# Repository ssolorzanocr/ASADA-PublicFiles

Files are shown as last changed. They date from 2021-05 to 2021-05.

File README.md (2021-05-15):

LoRa based control and log system for ASADA-Samara
============

### Most recent version of this repository can be found in: ###

* [ASADA-PublicFiles](https://github.com/ssolorzanocr/ASADA-PublicFiles)

### What is this repository for? ###

* This repository was created to develop LoRa based embedded control solution for the pumps of ASADA-Samara. 

### HELTEC LoRa 32 board information

* [Documentation page](https://heltec.org/project/wifi-lora-32/)
* [Pinout diagram](https://resource.heltec.cn/download/WiFi_LoRa_32/WIFI_LoRa_32_V2.pdf)
* [Schematic](https://resource.heltec.cn/download/WiFi_LoRa_32/V2/WIFI_LoRa_32_V2(868-915).PDF)
* [ESP32 datasheet](https://www.espressif.com/sites/default/files/documentation/esp32_datasheet_en.pdf) 

### Enclousure

* [Page](https://www.se.com/es/es/product/NSYCRN33200P/spacial-crn-plain-door-with-mount.plate.-h300xw300xd200-ip66-ik10-ral7035../) 

### How do I get set up? ###

* Install Git
* Install Arduino IDE
* Install Heltec ESP32 Library in the Arduino Library Manager
Open Arduino IDE, then Select `Sketch`->`Include Library`->`Manage Libraries...`
Search `Heltec ESP32` and install it.
* Install Adafruit MQTT Library in the Arduino Library Manager
Open Arduino IDE, then Select `Sketch`->`Include Library`->`Manage Libraries...`
Search `Adafruit MQTT` and install it.

### Library source code and examples
* [Adafruit_MQTT_Library](https://github.com/adafruit/Adafruit_MQTT_Library)

### Contribution guidelines ###

* If you want to propose a review or need to modify the code for any reason first clone this [repository](https://github.com/ssolorzanocr/ASADA-PublicFiles) in your PC and create a new branch for your changes. Once your changes are complete and fully tested ask the administrator permission to push this new branch into the source.
* If you just want to do local changes instead you can download a zip version of the repository and do all changes locally in your PC. 

### Who do I talk to? ###

* [Juan J. Rojas](mailto:juan.rojas@itcr.ac.cr)
* [Sergio Solorzano](mailto:solorzanos117@gmail.com)

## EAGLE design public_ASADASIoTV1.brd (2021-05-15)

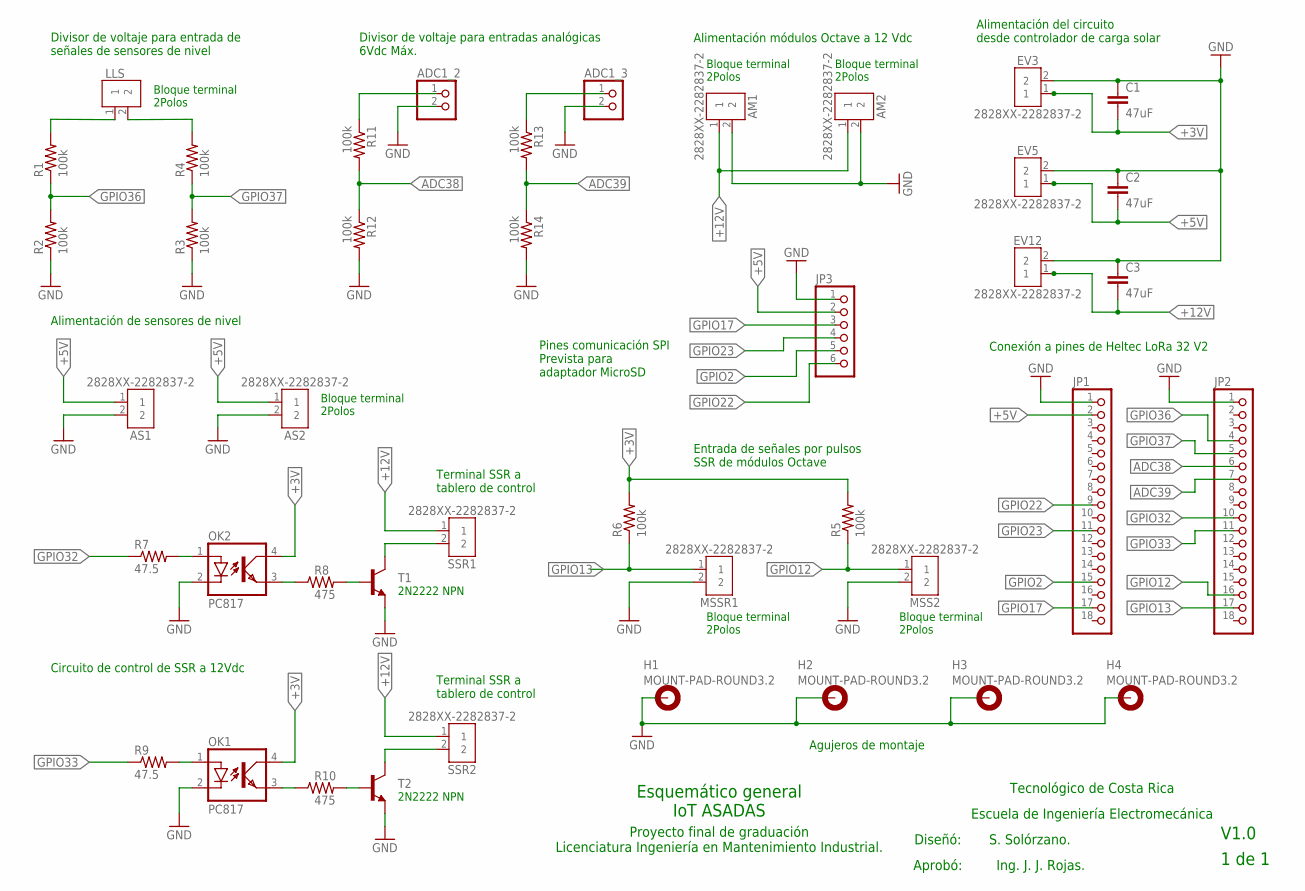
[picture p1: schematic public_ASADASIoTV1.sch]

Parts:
ADC1_2, ADC1_3: PINHD-1X2; 1X02
AM1, AM2: 2828XX-2282837-2; TERMBLK_508-2N
AS1, AS2: 2828XX-2282837-2; TERMBLK_508-2N
C1, C2, C3: 47uF; C2.5-5
EV3, EV5, EV12: 2828XX-2282837-2; TERMBLK_508-2N
H1, H2, H3, H4: MOUNT-PAD-ROUND3.2; 3,2-PAD
JP1, JP2: PINHD-1X18; 1X18
JP3: PINHD-1X6; 1X06
LLS: 2828XX-2282837-2; TERMBLK_508-2N
MSS2: 2828XX-2282837-2; TERMBLK_508-2N
MSSR1: 2828XX-2282837-2; TERMBLK_508-2N
OK1, OK2: PC817; DIL04
R1, R2, R3, R4, R5, R6, R11, R12, R13, R14: 100k; R0805
R7, R9: 47.5; R0805
R8, R10: 475; R0805
SSR1, SSR2: 2828XX-2282837-2; TERMBLK_508-2N
T1, T2: 2N3904; TO92

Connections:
+3V: C1.2, EV3.1, OK1.4 (COL), OK2.4 (COL), R5.2, R6.2
+5V: AS1.1, AS2.1, C2.2, EV5.1, JP1.2, JP3.2
+12V: AM1.1, AM2.1, C3.2, EV12.1, SSR1.1, SSR2.1
ADC38: JP2.6, R11.2, R12.1
ADC39: JP2.7, R13.2, R14.1
GND: ADC1_2.2, ADC1_3.2, AM1.2, AM2.2, AS1.2, AS2.2, C1.1, C2.1, C3.1, EV3.2, EV5.2, EV12.2, H1.B3,2, H2.B3,2, H3.B3,2, H4.B3,2, JP1.1, JP2.1, JP3.1, MSS2.2, MSSR1.2, OK1.2 (C), OK2.2 (C), R2.1, R3.1, R12.2, R14.2, T1.3 (E), T2.3 (E)
GPIO2: JP1.15, JP3.5
GPIO12: JP2.16, MSS2.1, R5.1
GPIO13: JP2.17, MSSR1.1, R6.1
GPIO17: JP1.17, JP3.3
GPIO22: JP1.9, JP3.6
GPIO23: JP1.11, JP3.4
GPIO32: JP2.10, R7.1
GPIO33: JP2.11, R9.1
GPIO36: JP2.4, R1.1, R2.2
GPIO37: JP2.5, R3.2, R4.1
HLS: LLS.2, R4.2
LLS: LLS.1, R1.2
unnamed: OK2.1 (A), R7.2
unnamed: SSR1.2, T1.1 (C)
unnamed: R8.2, T1.2 (B)
unnamed: OK2.3 (EMIT), R8.1
unnamed: ADC1_3.1, R13.1
unnamed: ADC1_2.1, R11.1
unnamed: OK1.1 (A), R9.2
unnamed: R10.2, T2.2 (B)
unnamed: OK1.3 (EMIT), R10.1
unnamed: SSR2.2, T2.1 (C)

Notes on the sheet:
Terminal SSR a tablero de control
Entrada de señales por pulsos SSR de módulos Octave
Alimentación de sensores de nivel
Divisor de voltaje para entrada de señales de sensores de nivel
Alimentación módulos Octave a 12 Vdc
Divisor de voltaje para entradas analógicas 6Vdc Máx.
Alimentación del circuito desde controlador de carga solar
Pines comunicación SPI Prevista para adaptador MicroSD
Agujeros de montaje
Conexión a pines de Heltec LoRa 32 V2
Circuito de control de SSR a 12Vdc
V1.0
1 de 1
Proyecto final de graduación Licenciatura Ingeniería en Mantenimiento Industrial.
Diseñó:
S. Solórzano.
Aprobó:
Ing. J. J. Rojas.
Escuela de Ingeniería Electromecánica
Tecnológico de Costa Rica
Esquemático general IoT ASADAS
2N2222 NPN
Bloque terminal 2Polos

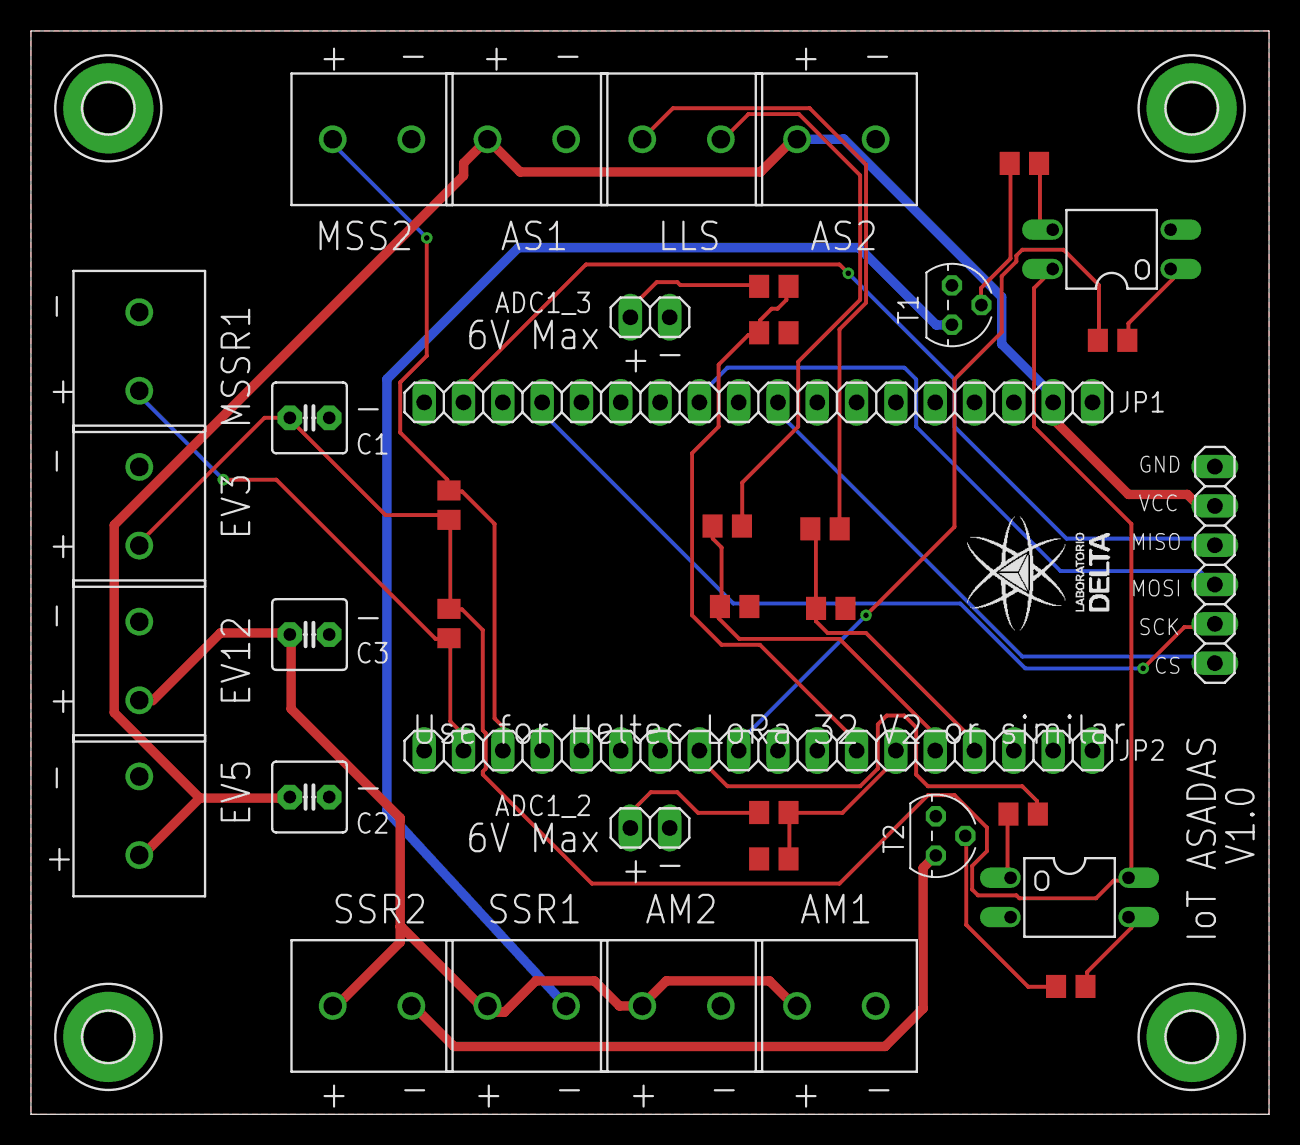
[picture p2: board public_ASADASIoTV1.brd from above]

Board: 2 copper layers, 80.0 x 70.0 mm, 42 parts (0 on the bottom side), 28 nets.

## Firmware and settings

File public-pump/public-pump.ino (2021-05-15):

/**
 * @file pump.ino
 * @author Sergio Solórzano Alfaro
 * @author Juan J. Rojas 
 * @date 15 May 2021
 * @brief Main loop for pump controller and 2 water meter data extraction
 * @par Institution:
 * DeltaLab. Instituto Tecnológico de Costa Rica.
 * @par mail:
 * solorzanos117@gmail.com
 * juan.rojas@tec.ac.cr
 * @par Git repository:
 * https://github.com/ssolorzanocr/ASADA-PublicFiles
 */

/*SS: IMPORTANT: When using GPIO pins to receive PWM signals and sending by LoRa, I recommend using pins 12 and 13. 
*Any other may have internal hardware interference*/

#include "heltec.h"
#include "soc/rtc.h"
#include "FS.h"
#include "SD.h"
#include <SPI.h>
#include <time.h>

#define BAND    915E6   //you can set band here directly,e.g. 868E6 (Europe),915E6 (North America),433E6 (Asia)

//Micro TF card pins to ESP32 GPIOs via this connecthin:
#define SD_CS   22        //  SD_CS   -- GPIO22
#define SD_SCK  2         //  SD_SCK  -- GPIO2
#define SD_MOSI 23        //  SD_MOSI -- GPIO23
#define SD_MISO 17        //  SD_MISO -- GPIO17

#define DIGITAL_PULSE_1 13  //for hidric measures  
#define DIGITAL_PULSE_2 12  //for hidric measures
#define ADC_BATTERY     38  //battery voltage input
#define ADC_INPUT       39  //foreseen input

#define DIGITAL_INPUT_1 36  //for 15hp pump contactor relay state
#define DIGITAL_INPUT_2 37  //for 10hp pump contactor relay state 

#define DIGITAL_SSROUT_1 32  //to activate 15hp pump contactor relay 
#define DIGITAL_SSROUT_2 33  //to activate 10hp pump contactor relay 

#define RP1     0.01          //IMPORTANT: Rp stands for "Pulse Resolution". Depends on flow meter parameters. 1 pulse = Rp cubic meters of water that have passed.
#define RP2     0.01
#define UNITS   1000000000.0  //calculate flow: (1000000000*Rp/(sum_interval/pulses))[m3/s]; (3600000000*Rp/(sum_interval/pulses))[m3/h]; (1000000000*Rp/(sum_interval/pulses))[L/s]

// The sd card can also use a virtual SPI bus
SPIClass sd_spi(HSPI);
long timezone = 1;
byte daysavetime = 1;

char t_stamp[20]; char buff[70] = {'\0'}; char value[20]; char semicolon[] = ";"; char newline[] = "\n"; char tank_rssi[10] = {'\0'};


TaskHandle_t measureTask;
TaskHandle_t loopTask;

/*----Local variables----*/    
byte localAddress;    // address of this device
byte destination;     // destination to send to (Gateway)
String incoming;

char *strtok(char *str1, const char *str2); char *part; char charpacket [80]; char delimiter [2] = "e";
String packSize = "--"; String sdelimiter="e";
char *s; int8_t packflag; 
char mpack[] = {'\0'};
char ppack[8] = {'\0'};

String pump15hp_status, pump1 = "OFF";
String pump10hp_status, pump2 = "OFF";
double battery_voltage, battery_life;
double pump15hp_flow, pump15hp_vol, pump15hp_vol_sent, pump10hp_flow, pump10hp_vol, pump10hp_vol_sent, av15hp_flow, av10hp_flow;

uint32_t t1_interval, t2_interval, sum1_interval, init_1stamp, sum2_interval, init_2stamp, last1interval, last2interval, lastorder;
bool first_1flag = 0; bool first_2flag = 0; bool firstflow1_flag, firstflow2_flag;
bool meter_1flag, meter_2flag;
/* create a hardware timer */
hw_timer_t * timer = NULL;
bool timer_flag, sd_flag; bool message_flag = 0;


int8_t txPower = 20;       /*txPower -- 0 ~ 20 dBm*/
/** LoRa.setTxPower(txPower,RFOUT_pin);
  * txPower -- 0 ~ 20
  * RFOUT_pin could be RF_PACONFIG_PASELECT_PABOOST or RF_PACONFIG_PASELECT_RFO
  *   - RF_PACONFIG_PASELECT_PABOOST -- LoRa single output via PABOOST, maximum output 20dBm
  *   - RF_PACONFIG_PASELECT_RFO     -- LoRa single output via RFO_HF / RFO_LF, maximum output 14dBm
  */ 

void IRAM_ATTR pulsecountA(){ 
  meter_1flag = 1;
}
void IRAM_ATTR pulsecountB(){ 
  meter_2flag = 1;
}

void IRAM_ATTR timer_isr(){
  timer_flag = 1;
}

void setup() {
  Serial.begin(115200);
  delay(10);
  noInterrupts();     //Disable interrupts while initiating 
  pinMode(DIGITAL_PULSE_1, INPUT_PULLUP); pinMode(DIGITAL_PULSE_2, INPUT_PULLUP); 
  pinMode(DIGITAL_SSROUT_1,OUTPUT); pinMode(DIGITAL_SSROUT_2,OUTPUT);
  pinMode(DIGITAL_INPUT_1,INPUT); pinMode(DIGITAL_INPUT_2,INPUT);
  attachInterrupt(DIGITAL_PULSE_1,&pulsecountA,RISING);      //(Interrupción (GPIO13),función,Flanco de subida)
  attachInterrupt(DIGITAL_PULSE_2,&pulsecountB,RISING);
  
  /* 1 tick take 1/(80MHZ/80) = 1us so we set divider 80 and count up */
  timer = timerBegin(0, 80, true);
  /* Attach timer_isr function to our timer */
  timerAttachInterrupt(timer, &timer_isr, true);
  /* Set alarm to call onTimer function every second 1 tick is 1us
  => 1 second is 1000000us */
  /* Repeat the alarm (third parameter) */
  timerAlarmWrite(timer, 5000000, true);
  /* Start an alarm */
  timerAlarmEnable(timer);

  Heltec.begin(true /*DisplayEnable Enable*/, true /*Heltec.Heltec.Heltec.LoRa Disable*/, true /*Serial Enable*/, true /*PABOOST Enable*/, BAND /*long BAND*/);
  Heltec.display->init();
  Heltec.display->setTextAlignment(TEXT_ALIGN_LEFT);
  Heltec.display->setFont(ArialMT_Plain_10); Heltec.display->flipScreenVertically();  
  Heltec.display->clear();
  Heltec.display->drawString(0, 0, "Heltec.LoRa Initial success!");
  Heltec.display->drawString(0, 20, "Beginning PUMP program!");
  Heltec.display->display();
  Serial.print("setup running on core "); Serial.println(xPortGetCoreID());
  
  //create a task that will be executed in the measureTaskcode() function, with priority 1 and executed on core 1
  xTaskCreatePinnedToCore(
                    measureTaskcode,  /* Task function. */
                    "measure",        /* name of task. */
                    10000,            /* Stack size of task */
                    NULL,             /* parameter of the task */
                    1,                /* priority of the task */
                    &measureTask,     /* Task handle to keep track of created task */
                    1);               /* pin task to core */                  
  delay(200);

  //create a task that will be executed in the loopTaskcode() function, with priority 1 and executed on core 0
  xTaskCreatePinnedToCore(
                    loopTaskcode,   /* Task function. */
                    "loop",         /* name of task. */
                    10000,          /* Stack size of task */
                    NULL,           /* parameter of the task */
                    1,              /* priority of the task */
                    &loopTask,      /* Task handle to keep track of created task */
                    0);             /* pin task to core */                  
  delay(200);

  // SD Card productionData.csv file initiation
  sd_spi.begin(SD_SCK, SD_MISO, SD_MOSI, SD_CS);

  if (!SD.begin(SD_CS, sd_spi)){
      Serial.println("SD Card: mounting failed.");
  } else {
      Serial.println("SD Card: mounted.");
  }
  uint8_t cardType = SD.cardType();

  if(cardType == CARD_NONE){
      Serial.println("No SD card attached");
      sd_flag=0;
      return;   //exit setup
  }else{
    sd_flag=1;
  }

  Serial.print("SD Card Type: ");
  if(cardType == CARD_MMC){
      Serial.println("MMC");
  } else if(cardType == CARD_SD){
      Serial.println("SDSC");
  } else if(cardType == CARD_SDHC){
      Serial.println("SDHC");
  } else {
      Serial.println("UNKNOWN");
  }
  uint64_t cardSize = SD.cardSize() / (1024 * 1024);
  Serial.printf("SD Card Size: %lluMB\n", cardSize);

  //For new SD Cart use only
  //deleteFile(SD, "/productionData.csv");
  //writeFile(SD, "/productionData.csv", "time;Flw1;Vol1;Flw2;Vol2;VBat\n");
  
  readFile(SD, "/productionData.csv");
  delay(500);
}


void measureTaskcode( void * pvParameters ){
  delay(6000);        //waits for everything else to start
  Serial.print("measureTask() running on core "); Serial.println(xPortGetCoreID());
  interrupts();       //Enable interrupts
  
  for(;;){            //measure loop for 2 simultaneous Octave water meters
    //After 71.6 minutes (2^32 micro seconds), the value you get from micros() will overflow (reset to zero).
    //Acording to Octave –After 1 minute of no flow, the meter will flash a series of letters and numbers in place of the rate of flow to show the checksum of the software version. 
    
    if(first_1flag){                         //Check only when measuring
      if ((micros()-init_1stamp)>120000000){  //Stop and reset measure process after 2 minutes of no PULSES. **Min flow posibly measured = RP*1000/120 [L/s]
        first_1flag=0; 
        pump15hp_flow = 0;
        sum1_interval+=(micros()-init_1stamp);    //Add last large time interval for average calc 
        if (firstflow1_flag){
          av15hp_flow = UNITS*(pump15hp_vol-RP1)/(double)sum1_interval; //minus Rp cause first pulse measure does not count for first flow calc
        }else{
          av15hp_flow = UNITS*(pump15hp_vol)/(double)sum1_interval;
        }
        Serial.println("Stop 15hp");              //Measuring process stops in order to save memory

        //printing >>>
        //time,interval between pulses (us),vol(m3),flow(L/s),promflow(L/s),interval between pulses (us),vol(m3),flow(L/s),promflow(L/s),battery voltage
        Serial.print(",");Serial.print(last1interval);Serial.print(","); Serial.print (pump15hp_vol,3); Serial.print(","); 
        Serial.print (pump15hp_flow,4); Serial.print(","); Serial.print(av15hp_flow,4); Serial.print(", , , , ,"); 
        Serial.println(battery_voltage,4);
        Serial.println(sum1_interval);
      }
    }
    if(first_2flag){                         //Check only when measuring
      if ((micros()-init_2stamp)>120000000){  //Stop and reset measure process after 2 minutes of no PULSES. **Min flow posibly measured = RP*1000/120 [L/s]
        first_2flag=0; 
        pump10hp_flow = 0;
        sum2_interval+=(micros()-init_2stamp);    //Add last large time interval for average calc 
        if (firstflow2_flag){
          av10hp_flow = UNITS*(pump10hp_vol-RP2)/(double)sum2_interval; //minus Rp cause first pulse measure does not count for first flow calc
        }else{
          av10hp_flow = UNITS*(pump10hp_vol)/(double)sum2_interval;
        }
        Serial.println("Stop 10hp");              //Measuring process stops in order to save memory

        //printing >>>
        //time,interval between pulses (us),vol(m3),flow(L/s),promflow(L/s),interval between pulses (us),vol(m3),flow(L/s),promflow(L/s),battery voltage
        Serial.print(", , , , ,"); 
        Serial.print(last2interval);Serial.print(","); Serial.print (pump10hp_vol,3); Serial.print(","); 
        Serial.print (pump10hp_flow,4); Serial.print(","); Serial.print(av10hp_flow,4); Serial.print(",");
        Serial.println(battery_voltage,4);
        Serial.println(sum2_interval);
      }
    }
    
    //Start measures
    if(meter_1flag && !first_1flag){  //Start 15hp measure process 
      first_1flag=1; meter_1flag=0; firstflow1_flag=1; Serial.println("Start 15hp");
      init_1stamp=micros();          //First time stamp
      pump15hp_vol+= RP1;                     //First volume measure
    }
    if(meter_2flag && !first_2flag){  //Start 10hp measure process 
      first_2flag=1; meter_2flag=0; firstflow2_flag=1; Serial.println("Start 10hp");
      init_2stamp=micros();          //First time stamp
      pump10hp_vol+= RP2;                     //First volume measure
    }
    
    //Measuring volume and flow process for 15hp pump
    if(meter_1flag && first_1flag ){
      t1_interval=abs(micros()-init_1stamp);  //Time interval between pulses
      if (t1_interval<110000){       //IGNORE SMALL INTERFERENCES, THAT CAUSES HUGE FLOW MEASURES < 0.3 sec 
        //IMPORTANT: THIS PARAMETER MUST BE A LITTLE BIT LARGER THAN PULSE WIDTH ---> SMALL PULSE WIDTHS HELPS AT MEASURING
        //pulse width measured for 4in Octave is 450ms and for 2in Octave is 300ms
        //pulse width programed for 4in Octave is 90ms and for 2in Octave is 280ms
        meter_1flag=0;
      }else{
        init_1stamp=micros();        //Time stamp for next measure
        sum1_interval+=t1_interval;   //For average flow calc
        
        pump15hp_flow = (UNITS*RP1)/((double)t1_interval); 
        
        pump15hp_vol+= RP1;                                 //plus Rp cubic meters per interruption

        if (firstflow1_flag){
          av15hp_flow = UNITS*(pump15hp_vol-RP1)/(double)sum1_interval; //minus Rp cause first pulse measure does not count for first flow calc
        }else{
          av15hp_flow = UNITS*(pump15hp_vol)/(double)sum1_interval;
        }
        meter_1flag=0; last1interval= t1_interval;
        
        //printing >>>
        //time,interval between pulses (us),vol(m3),flow(L/s),promflow(L/s),interval between pulses (us),vol(m3),flow(L/s),promflow(L/s),battery voltage
        Serial.print(",");Serial.print(last1interval);Serial.print(","); Serial.print (pump15hp_vol,3); Serial.print(","); 
        Serial.print (pump15hp_flow,4); Serial.print(","); Serial.print(av15hp_flow,4); Serial.print(", , , , ,"); 
        Serial.println(battery_voltage,4);
        Serial.println(sum1_interval);
      } 
    }
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
void loop () {
  delay(1000);
}
/*--------------------------------------------------------------------------------------------*/

/*-------------------------------------LoRa functions----------------------------------------*/

void LoRaSend(String outgoing, byte destination) {
  Heltec.display->drawString(0, 30, outgoing);
  Heltec.display->display();
  delay(1000);                   
  for(int i = 0; i < 4; i++){ // send same packet 4 times (2 seconds in total)
    LoRa.beginPacket();
    LoRa.setTxPower(txPower,RF_PACONFIG_PASELECT_PABOOST);
    // Packet header bytes:
    LoRa.write(destination);              // add destination address
    LoRa.write(localAddress);             // add sender address
    LoRa.write(outgoing.length());        // add payload length
    // add payload
    LoRa.print(outgoing);                 
    LoRa.endPacket();
    Serial.print("Sent  "); Serial.println(outgoing);
    delay(500);
  }
  delay(500); //rest half second                 
}

void listencommand(){ /*LISTENING STATE*/
  packflag = 0;
  
  LoRa.receive();
  onReceive(LoRa.parsePacket());
  
  //Serial.print("incoming  "); Serial.println(incoming);
 
  if (message_flag){
    message_flag=0; 
    Heltec.display->drawString(0, 40, incoming); Heltec.display->display();
    //Serial.print("Incoming length: "); Serial.println(incoming.length());
    if (incoming.length()<=3){
      if (incoming=="P"){
        packflag = 1;        
      }
      if (incoming=="SP"){
        packflag = 2;        
      }
      if (incoming=="OKP"){ //reset average flow calc and acumulated volume
        sum1_interval=0; sum2_interval=0; av15hp_flow=0; av10hp_flow=0;
        pump15hp_vol-=pump15hp_vol_sent; pump10hp_vol-=pump10hp_vol_sent;  
        delay(2000);  //wait for repeated messages to pass
        pump15hp_vol_sent=0; pump10hp_vol_sent=0; firstflow1_flag=0; firstflow2_flag=0;      
      }
    }else{
      packflag = 2;
    }
  }
  //Serial.print("packflag  "); Serial.println(packflag);
}

void onReceive(int packetSize){
  if (!packetSize) {
    //Serial.println("No order");
    if ((millis()-lastorder)>600000){
      //10 minutes since no order from gateway master -> turn off all pumps
      if ((pump1!="OFF")||(pump2!="OFF")){
        digitalWrite(DIGITAL_SSROUT_1, LOW);
        digitalWrite(DIGITAL_SSROUT_2, LOW);
        pump1= "OFF"; pump2 = "OFF";
      }
      Heltec.display->drawString(0, 40,"error: No order in 10min"); Heltec.display->display();
    }
    return;                             // if there's no packet, return
  }

  // read packet header bytes:
  int recipient = LoRa.read();          // recipient address
  byte sender = LoRa.read();            // sender address
  byte incomingLength = LoRa.read();    // incoming msg length

  incoming ="";
  while (LoRa.available()){
    incoming += (char)LoRa.read();
  }
  
  if (incomingLength != incoming.length()){   // check length for error
      Heltec.display->drawString(0, 40,"error: length does not match"); Heltec.display->display();
      Serial.println("error: message length does not match length");
    }
  
  // if the recipient isn't this device or sender isn't gateway,
  if (recipient != localAddress && sender != destination) {
      Heltec.display->drawString(0, 40,"error: message not for me"); Heltec.display->display();
      Serial.println("Message not for me");
    }
  if (recipient == localAddress && sender == destination && incomingLength == incoming.length()) {
    message_flag=1; 
    Heltec.display->drawString(60, 40, "RSSI: " + String(LoRa.packetRssi())); Heltec.display->display();
    sprintf(tank_rssi, "%d", LoRa.packetRssi());
    //Received Signal Strength Indicator (RSSI) - closer the value is to 0, the stronger the received signal has been. 
    // if message is for this device, or broadcast, print details:
    Serial.println("----------------------------------------");
    Serial.println("Received from: 0x" + String(sender, HEX));
    Serial.println("Sent to: 0x" + String(recipient, HEX));
    Serial.println("Message length: " + String(incomingLength));
    Serial.println("Message: " + incoming);
    Serial.println("RSSI: " + String(LoRa.packetRssi()));
    Serial.println("Snr: " + String(LoRa.packetSnr()));
    Serial.println("----------------------------------------");
  }
}
/*-------------------------------------------------------------------------------------------*/

void pumpcheck(){
  if (digitalRead(DIGITAL_INPUT_1)){        //checks main pump contactor state
    pump15hp_status = "ON";
  }else{
    pump15hp_status = "OFF";
  }
  if (digitalRead(DIGITAL_INPUT_2)){        //checks secondary pump contactor state
    pump10hp_status = "ON";
  }else{
    pump10hp_status = "OFF";
  }
  if (pump15hp_status != pump1 || pump10hp_status != pump2){
    Serial.println("ERROR en BOMBAS o modo manual activo");
    Heltec.display->drawString(0, 40, "ALERTA! MODO MANUAL");
    Heltec.display->display();
  }
}

void batteryVoltage(){
  /*full battery voltage = 4.17V, which corresponds to a reading of 2.085V
   *empty battery voltage = 2.90V, which corresponds to a reading of 1.4V
   */ 
  battery_voltage=2*((analogRead(ADC_BATTERY)+200.01)/1263.4); // Aproximate ADC vs DC voltage function from Heltec LoRa 32 V2 real measures   
  battery_life=100*((battery_voltage-2.9)/1.27); //percentage 
  if (battery_life>100){ battery_life=100;}
  if (battery_life<0){ battery_life=0;}
  //Serial.print("\tBattery: "); Serial.print(battery_voltage,4); Serial.print("\t"); Serial.println(battery_life);
}

/*--------------------------------------------------------------------------------------------*/

/*-------------------------Micro SD Card Data log functions-----------------------------------*/

void readFile(fs::FS &fs, const char * path){
  Serial.printf("Reading file: %s\n", path);

  File file = fs.open(path);
  if(!file){
      Serial.println("Failed to open file for reading");
      deleteFile(SD, "/productionData.csv");
      writeFile(SD, "/productionData.csv", "time;Flw1;Vol1;Flw2;Vol2;VBat\n");  //if there is no file to read, create one
      return;
  }

  Serial.print("Read from file: ");
  while(file.available()){
      Serial.write(file.read());
  }
  file.close();
}

void writeFile(fs::FS &fs, const char * path, const char * message){
  Serial.printf("Writing file: %s\n", path);

  File file = fs.open(path, FILE_WRITE);
  if(!file){
      Serial.println("Failed to open file for writing");
      return;
  }
  if(file.print(message)){
      Serial.println("File written");
  } else {
      Serial.println("Write failed");
  }
  file.close();
}

void appendFile(fs::FS &fs, const char * path, const char * message){
  Serial.printf("Appending to file: %s\n", path);

  File file = fs.open(path, FILE_APPEND);
  if(!file){
      Serial.println("Failed to open file for appending");
      return;
  }
  if(file.print(message)){
      Serial.println("Message appended");
  } else {
      Serial.println("Append failed");
  }
  file.close();
}

void renameFile(fs::FS &fs, const char * path1, const char * path2){
  Serial.printf("Renaming file %s to %s\n", path1, path2);
  if (fs.rename(path1, path2)) {
      Serial.println("File renamed");
  } else {
      Serial.println("Rename failed");
  }
}

void deleteFile(fs::FS &fs, const char * path){
  Serial.printf("Deleting file: %s\n", path);
  if(fs.remove(path)){
      Serial.println("File deleted");
  } else {
      Serial.println("Delete failed");
  }
}
/*-------------------------------------------------------------------------------------------*/

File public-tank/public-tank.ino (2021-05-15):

/**
 * @file tank.ino
 * @author Sergio Solórzano Alfaro 
 * @coauthor Juan José Rojas
 * @date 15 May 2021
 * @brief Main loop is a state machine firmware for tank monitoring and LoRa Gateway
 * @par Institution:
 * DeltaLab. Instituto Tecnológico de Costa Rica.
 * @par mail:
 * solorzanos117@gmail.com
 * juan.rojas@tec.ac.cr
 * @par Git repository:
 * https://github.com/ssolorzanocr/ASADA-PublicFiles
 */
// JR: VERY Important ADC2 pins cannot be used when the WiFi is being used, and some of the ADC1 pins are also blocked for some reason, 32, 33 and 39 are ok...
/*SS: IMPORTANT: When using GPIO pins to receive PWM signals while using WiFi, I recommend using pin 2 and 17. 
*Any other may have internal hardware interference
*IMPORTANT >> Both High Level and Low Level sensors must be High in Air!*/

#include "heltec.h" 
#include <WiFi.h>
#include "Adafruit_MQTT.h"
#include "Adafruit_MQTT_Client.h" 
#include "soc/rtc.h"
#include "FS.h"
#include "SD.h"
#include <SPI.h>
#include <time.h>

#define BAND    915E6   //you can set band here directly,e.g. 868E6 (Europe),915E6 (North America),433E6 (Asia)

#define WLAN_SSID       //name of your wifi                      
#define WLAN_PASS       //your wifi password              
#define AIO_SERVER      //adafruit server 
#define AIO_SERVERPORT  //the server number                 
#define AIO_USERNAME    //your adafruit IO username
#define AIO_KEY         //your adafruit IO key

//Micro TF card pins to ESP32 GPIOs via this connecthin:
#define SD_CS   22        //  SD_CS   -- GPIO22
#define SD_SCK  2         //  SD_SCK  -- GPIO2
#define SD_MOSI 23        //  SD_MOSI -- GPIO23
#define SD_MISO 17        //  SD_MISO -- GPIO17

#define DIGITAL_PULSE_1 13  //for hidric measures  

#define ADC_BATTERY     39  //battery voltage input
#define ADC_INPUT       38  //foreseen input     

#define DIGITAL_INPUT_1 36  //for low liquid level sensor 
#define DIGITAL_INPUT_2 37  //for high liquid level sensor 

#define RP      0.001          //IMPORTANT: Rp stands for "Pulse Resolution". Depends on flow meter parameters. 1 pulse = Rp cubic meters of water that have passed.
#define UNITS   1000000000.0  //calculate flow: (1000000*Rp/(sum_interval/pulses))[m3/s]; (3600000000*Rp/(sum_interval/pulses))[m3/h]; (1000000000*Rp/(sum_interval/pulses))[L/s]

/*-------- Core temperature variables -------*/
#ifdef __cplusplus
extern "C" {
#endif
uint8_t temprature_sens_read();
#ifdef __cplusplus
}
#endif
uint8_t temprature_sens_read();
/*------------------------------*/


WiFiClient client;
Adafruit_MQTT_Client mqtt(&client, AIO_SERVER, AIO_SERVERPORT, AIO_USERNAME, AIO_KEY);

//IoT sistem water data
Adafruit_MQTT_Publish statusauto = Adafruit_MQTT_Publish(&mqtt, AIO_USERNAME "/feeds/statusauto");       
Adafruit_MQTT_Publish status15hp = Adafruit_MQTT_Publish(&mqtt, AIO_USERNAME "/feeds/pumps.status15hp");
Adafruit_MQTT_Publish status10hp = Adafruit_MQTT_Publish(&mqtt, AIO_USERNAME "/feeds/pumps.status10hp");
Adafruit_MQTT_Publish dmndflow = Adafruit_MQTT_Publish(&mqtt, AIO_USERNAME "/feeds/water.dmndflow");
Adafruit_MQTT_Publish dmndvol = Adafruit_MQTT_Publish(&mqtt, AIO_USERNAME "/feeds/water.dmndvol");
Adafruit_MQTT_Publish prodflow = Adafruit_MQTT_Publish(&mqtt, AIO_USERNAME "/feeds/water.prodflow");
Adafruit_MQTT_Publish prodvol = Adafruit_MQTT_Publish(&mqtt, AIO_USERNAME "/feeds/water.prodvol");
Adafruit_MQTT_Publish alerts = Adafruit_MQTT_Publish(&mqtt, AIO_USERNAME "/feeds/alerts");
Adafruit_MQTT_Publish tanklvl = Adafruit_MQTT_Publish(&mqtt, AIO_USERNAME "/feeds/tanklvl");
Adafruit_MQTT_Publish lowsensor = Adafruit_MQTT_Publish(&mqtt, AIO_USERNAME "/feeds/lowsensor");
Adafruit_MQTT_Publish highsensor = Adafruit_MQTT_Publish(&mqtt, AIO_USERNAME "/feeds/highsensor");
Adafruit_MQTT_Publish mainrealwaterloses = Adafruit_MQTT_Publish(&mqtt, AIO_USERNAME "/feeds/mainrealwaterloses");

//IoT sistem LoRa and power funtion parameters data
Adafruit_MQTT_Publish volt2b = Adafruit_MQTT_Publish(&mqtt, AIO_USERNAME "/feeds/sistemaiot.volt2b"); 
Adafruit_MQTT_Publish volt3b = Adafruit_MQTT_Publish(&mqtt, AIO_USERNAME "/feeds/sistemaiot.volt3b"); 
Adafruit_MQTT_Publish volt4b = Adafruit_MQTT_Publish(&mqtt, AIO_USERNAME "/feeds/sistemaiot.volt4b"); 
Adafruit_MQTT_Publish rssimeter = Adafruit_MQTT_Publish(&mqtt, AIO_USERNAME "/feeds/sistemaiot.rssimeter"); 
Adafruit_MQTT_Publish rssipump = Adafruit_MQTT_Publish(&mqtt, AIO_USERNAME "/feeds/sistemaiot.rssipump");
Adafruit_MQTT_Publish tankcoretemp = Adafruit_MQTT_Publish(&mqtt, AIO_USERNAME "/feeds/sistemaiot.tankcoretemp"); 

Adafruit_MQTT_Subscribe control10hp = Adafruit_MQTT_Subscribe(&mqtt, AIO_USERNAME "/feeds/pumps.control10hp");
Adafruit_MQTT_Subscribe control15hp = Adafruit_MQTT_Subscribe(&mqtt, AIO_USERNAME "/feeds/pumps.control15hp");
Adafruit_MQTT_Subscribe automatic = Adafruit_MQTT_Subscribe(&mqtt, AIO_USERNAME "/feeds/automatic");

char *strtok(char *str1, const char *str2); char *part; 
char charpacket [99]; char delimiter [2] = "e"; char ppack[8] = "start";
String State="1"; String tank; String sdelimiter="e";

/*----Local variables----*/
String pump15hp_status="OFF", pump10hp_status="OFF";  //pump On/Off changing variable, start with everything OFF
String mem_pump15hp, mem_pump10hp;        //pump On/Off last value

int8_t attempt = 0; int packetSize; 
uint32_t interval, lastinterval, sum_interval, init_stamp;
bool meter_flag, sd_flag; bool pump10hp_flag=1; bool first_flag = 0; bool message_flag = 0; bool callback_flag, firstflow_flag; 
bool reset_flag; //for volumes daily reset  
 
byte localAddress;          // address of this device
byte meter_destination;      // Node 1 destination address
byte pump_destination;      // Node 2 destination address
String incoming; 

/*----AIO publish variables----*/
char alert_message [70]; String mem_alert_message, route;
double pump15hp_flow, pump15hp_vol, pump10hp_flow, pump10hp_vol;  //water production variables
double rdemand_flow, rdemand_vol, sumrdemand_flow, rdemand_av, demand_flow, demand_vol, product_publish, demand_publish;   //water demand variables (volume is accumulative)         
double tank_lvl, mrwl, upmrwl, product_total, demand_total, rdemand_memvol;   //for tank level calculation**
double tank_battery_voltage, tank_battery_life, prod_battery_voltage, prod_battery_life, demand_battery_voltage, demand_battery_life; 

/*----AIO subscription variables----*/
String IoTsystem, mem_IoTsystem, pump15hp_IO, pump10hp_IO; 

/* create a hardware timer */
hw_timer_t * timer = NULL; 

bool upload_flag, alert_flag, losscalc_flag; int8_t data_flag=0;
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
